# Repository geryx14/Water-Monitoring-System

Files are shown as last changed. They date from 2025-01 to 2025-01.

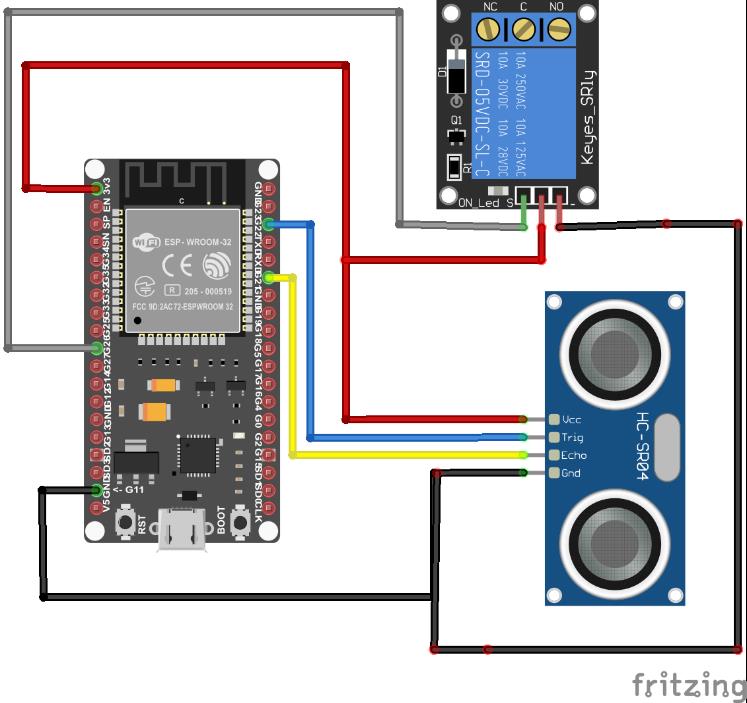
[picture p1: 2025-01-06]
Scematic Hardwere/Wiring ESP.jpg

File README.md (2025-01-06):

# IoT-Based Water Monitoring System

## Description
This project provides an affordable and efficient way to monitor water levels and quality using IoT technology. With real-time data transmission and cloud integration, it ensures better resource management.

## Key Features
- Real-time monitoring of water parameters
- Database integration for remote access
- Simple and scalable design
- to give saveral notifications alert to email and telegram

## Hardware Requirements
- ESP32 microcontroller
- Raspberry pi 4B
- ADS115 Analog Digital Converter
- Ultrasonic sensor (URM-09) : https://wiki.dfrobot.com/URM09_Ultrasonic_Sensor_(Gravity_Analog)_SKU_SEN0307
- Gravity: Analog Turbidity Sensor for Arduino LINK : https://www.dfrobot.com/product-1394.html?srsltid=AfmBOop4nN1BXaXB-rLAD9B4F6cB8y7F4hOIFvNodXXyrF563nFi_e-l
- Gravity: Analog pH Sensor / Meter Pro Kit for Arduino : https://www.dfrobot.com/product-1110.html
- DC PSU 5 Volt
- DC PSU 24 Volt
- Relay 5V DC
- Relay 3 fasa solidstate

## Required Libraries and Dependencies

To ensure the system works properly, install the following libraries and dependencies for ESP32, Raspberry Pi, and Node-RED.

### **ESP32 Libraries**
Ensure the following libraries are installed in the Arduino IDE or PlatformIO:

1. **WiFi Library**  
   - For ESP32 WiFi connectivity.  
   - Built-in with ESP32 core, or install via Board Manager.

2. **PubSubClient**  
   - For MQTT communication.  
   - Install via Arduino Library Manager:  
     ```
     Sketch > Include Library > Manage Libraries > Search for "PubSubClient"
     ```
3. **Ultrasonic sensor (URM-09)** 
   -For HC-SR04 ultrasonic sensor URM-09
   - Install via GitHub:  
     ```
       [[Ultrasonic](https://github.com/JRodrigoTech/Ultrasonic-HC-SR04](https://github.com/DFRobot/DFRobot_URM09))
     
     ```
### **Raspberry Pi Dependencies**
Install the following libraries or packages on your Raspberry Pi:

1. **I2C Communication**  
      first you must to active I2C Communication for raspberry pi
       1. "Sudo Raspi-config"
       2. Interface Options > I2C > Enable
     
4. **MQTT Library**
    Step two you must install MQTT library  
     sudo apt update
     sudo apt upgrade -y
     Sudo pip3 install paho-mqtt

3. **Sensor-Specific Libraries**  
   -For HC-SR04 ultrasonic sensor URM-09
   - Install via GitHub:  
     [[Ultrasonic](https://github.com/JRodrigoTech/Ultrasonic-HC-SR04](https://github.com/DFRobot/DFRobot_URM09))
   -for ADS115 Analog Digital Converter
    - Install via GitHub
      https://github.com/giobauermeister/ads1115-linux-rpi

### **Node-RED Dependencies**
Install the following custom nodes in Node-RED:

1. **Installation Steps:**  
    to use node-red with server for example install node-red in windows comment promt
    - npm install -g --unsafe-perm node-red

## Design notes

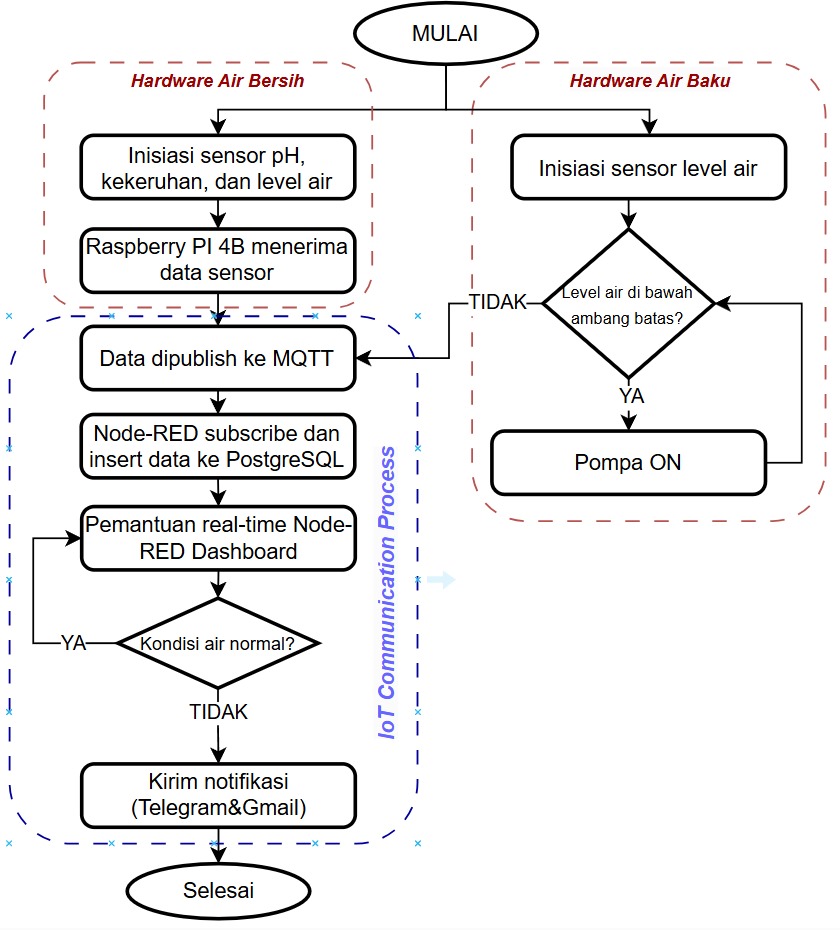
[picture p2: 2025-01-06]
Flow Chart.jpeg

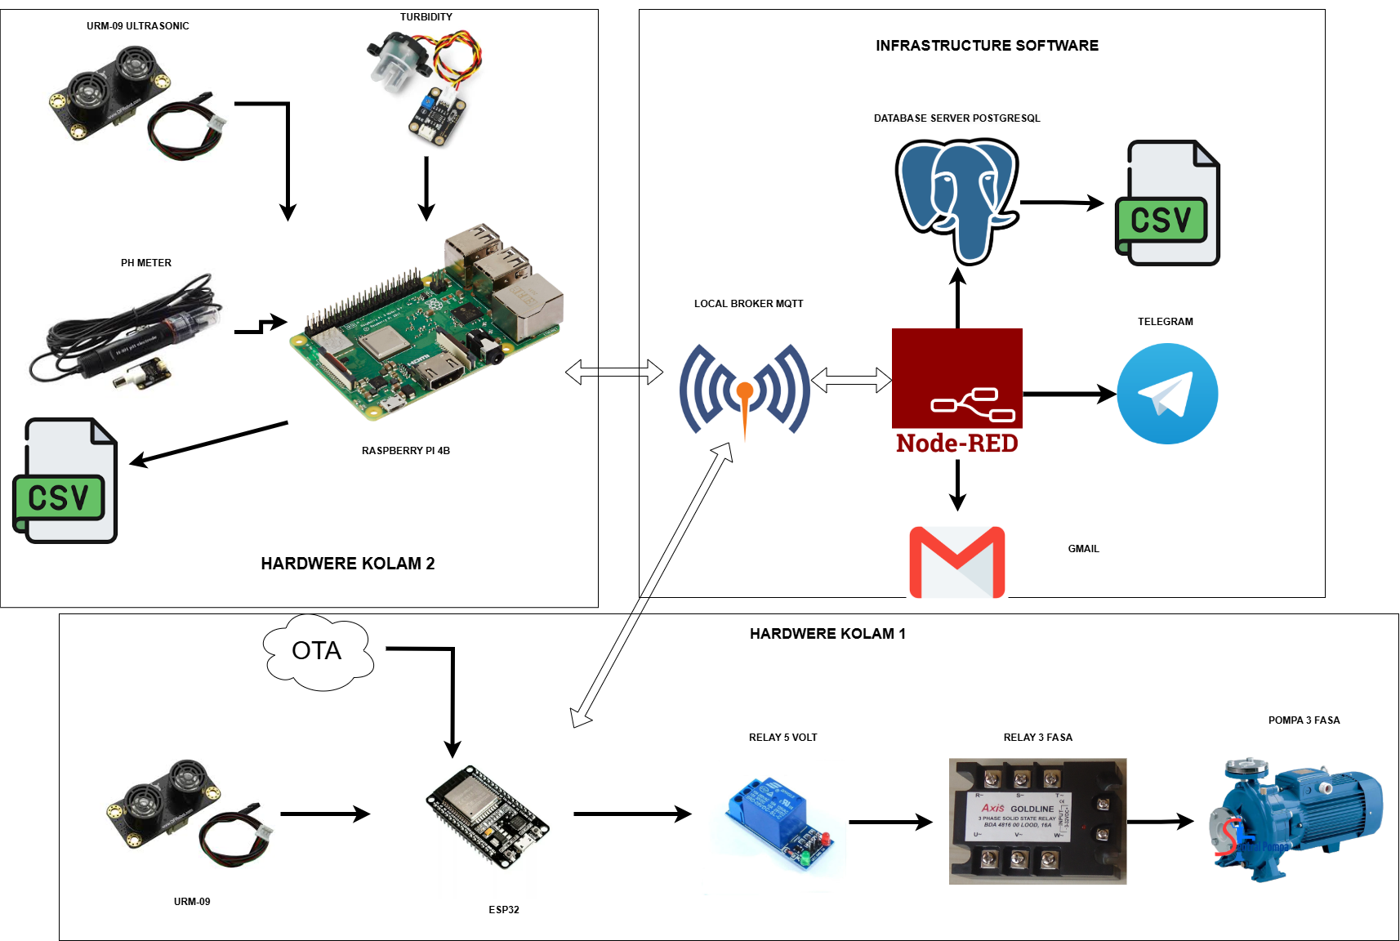
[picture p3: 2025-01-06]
Diagram Blok.png

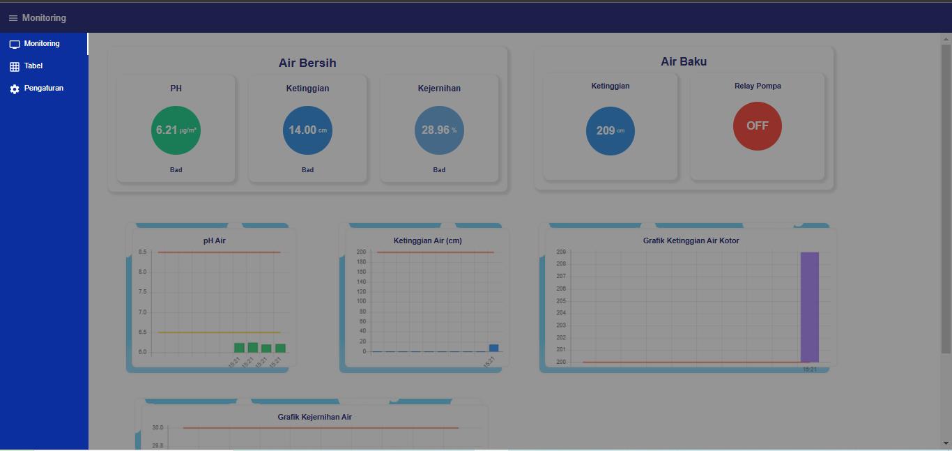
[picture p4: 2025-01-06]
Program Software/DASHBOARD.jpg

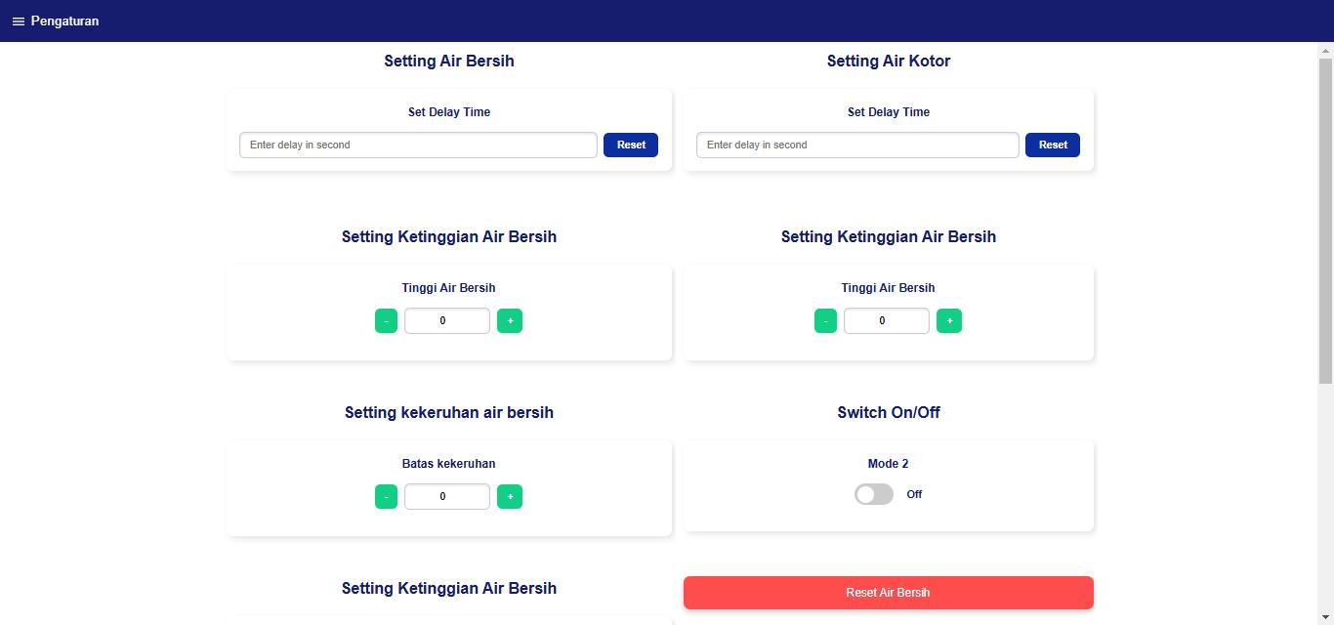
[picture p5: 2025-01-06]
Program Software/CONFIG.jpg

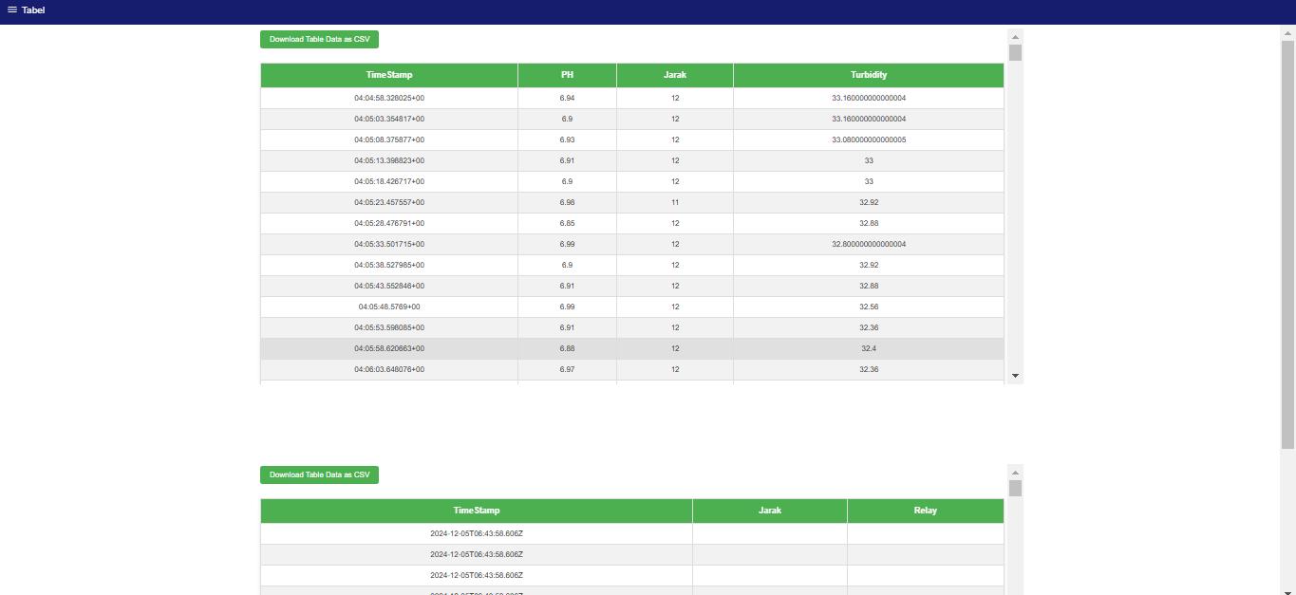
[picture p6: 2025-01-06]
Program Software/Database.jpg

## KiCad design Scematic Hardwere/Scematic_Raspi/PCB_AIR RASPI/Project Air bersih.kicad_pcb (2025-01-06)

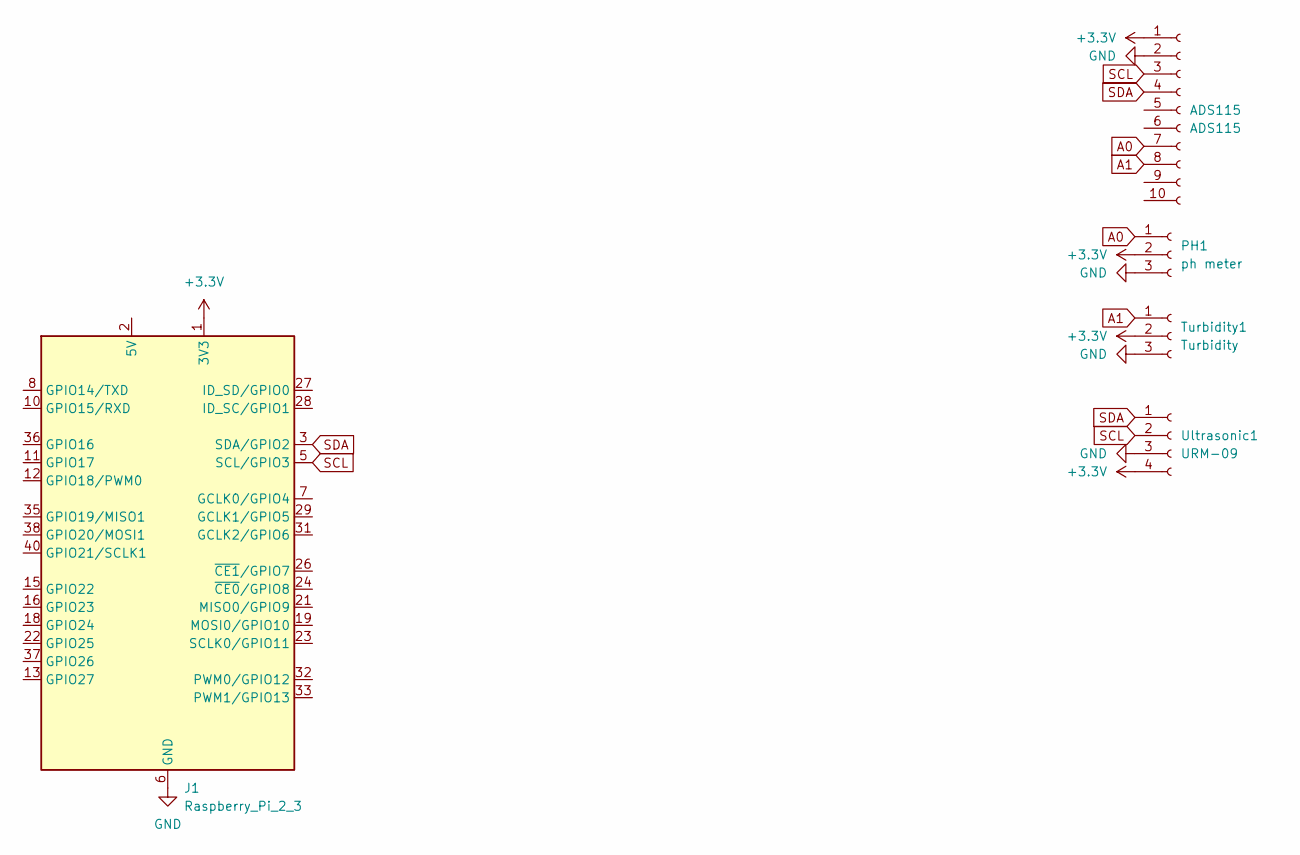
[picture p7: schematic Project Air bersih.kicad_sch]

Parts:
ADS115: ADS115; Hirose_DF13-10P-1.25DSA_1x10_P1.25mm_Vertical
J1: Raspberry_Pi_2_3; PinHeader_2x20_P2.54mm_Vertical
PH1: ph meter; JST_EH_B3B-EH-A_1x03_P2.50mm_Vertical
Turbidity1: Turbidity; JST_EH_B3B-EH-A_1x03_P2.50mm_Vertical
Ultrasonic1: URM-09; JST_EH_B4B-EH-A_1x04_P2.50mm_Vertical

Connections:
+3.3V: ADS115.1, J1.1 (3V3), J1.17 (3V3), PH1.2, Turbidity1.2, Ultrasonic1.4
A0: ADS115.7, PH1.1
A1: ADS115.8, Turbidity1.1
GND: ADS115.2, J1.6 (GND), J1.9 (GND), J1.14 (GND), J1.20 (GND), J1.25 (GND), J1.30 (GND), J1.34 (GND), J1.39 (GND), PH1.3, Turbidity1.3, Ultrasonic1.3
unnamed: J1.2 (5V), J1.4 (5V)
SCL: ADS115.3, J1.5 (SCL/GPIO3), Ultrasonic1.2
SDA: ADS115.4, J1.3 (SDA/GPIO2), Ultrasonic1.1

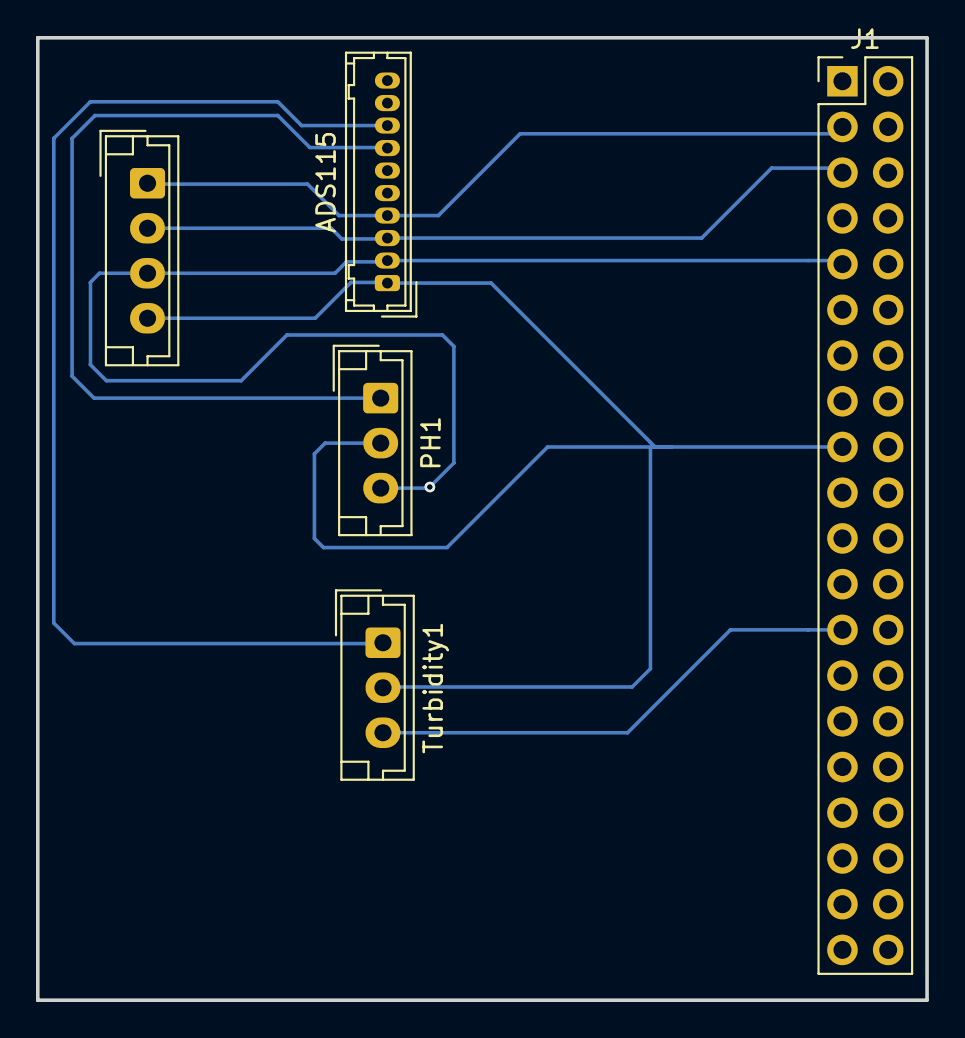
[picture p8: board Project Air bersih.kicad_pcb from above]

Board: 2 copper layers, 49.4 x 53.5 mm, 5 parts (0 on the bottom side), 7 nets.

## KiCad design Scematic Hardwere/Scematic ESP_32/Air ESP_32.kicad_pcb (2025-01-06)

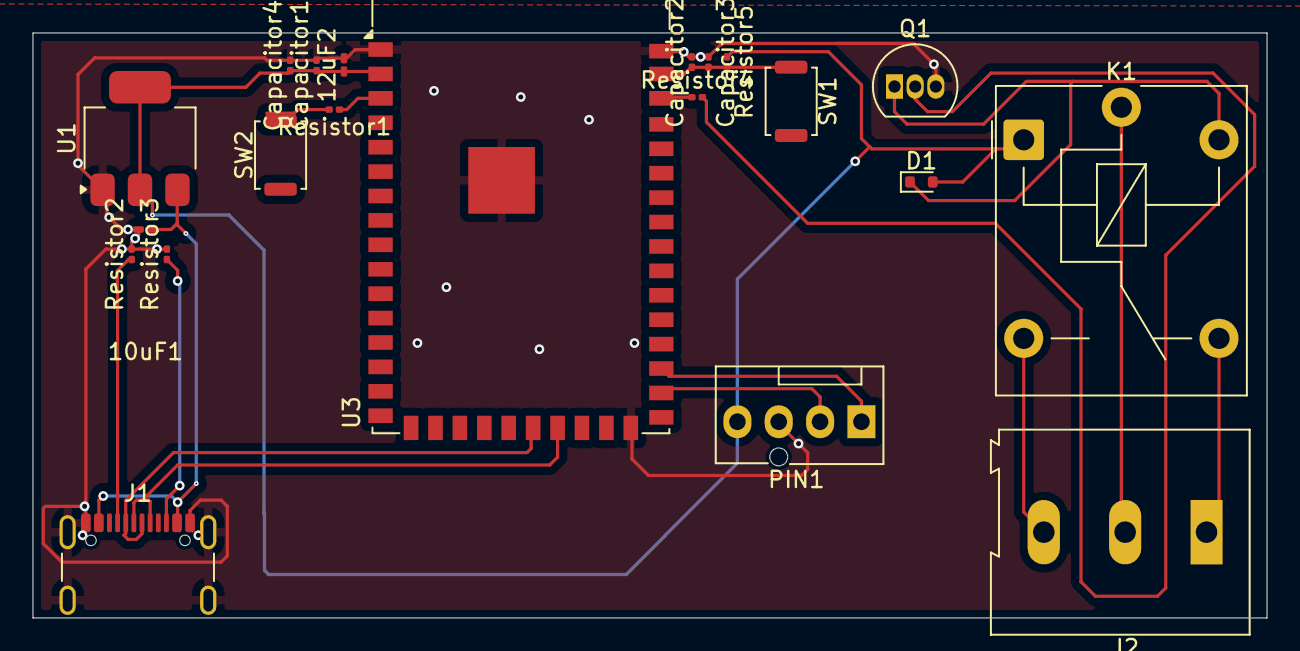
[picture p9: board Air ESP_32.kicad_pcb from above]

Board: 2 copper layers, 75.8 x 35.9 mm, 21 parts (0 on the bottom side), 18 nets.

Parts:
10uF1, 12uF2: c; C_0201_0603Metric_Pad0.64x0.40mm_HandSolder
Capacitor1: 10nf; C_0201_0603Metric
Capacitor2, Capacitor3: 1uF; C_0201_0603Metric
Capacitor4: 22uf; C_0201_0603Metric
D1: 1N4148WT; D_SOD-523
J1: USB_C_Receptacle_USB2.0_16P; USB_C_Receptacle_GCT_USB4105-xx-A_16P_TopMnt_Horizontal
J2: Screw_Terminal_01x03; TerminalBlock_Altech_AK300-3_P5.00mm
K1: FINDER-36.11; Relay_SPDT_Finder_36.11
PIN1: Ultrasonic URM-09; FanPinHeader_1x04_P2.54mm_Vertical
Q1: BC547; TO-92_Inline
Resistor1, Resistor4: 100R; R_0201_0603Metric
Resistor2, Resistor3, Resistor5: 10k; R_0201_0603Metric
SW1, SW2: SW_MEC_5G; SW_Push_SPST_NO_Alps_SKRK
U1: AMS1117; SOT-223-3_TabPin2
U3: ESP32-S2-WROVER

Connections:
+3.3V: 12uF2.1, Capacitor1.1, Capacitor4.1, D1.2 (A), K1.A1, PIN1.4, Resistor5.1, U1.2 (VO), U3.2 (3V3)
+5V: 10uF1.1, J1.A4 (VBUS), J1.A9 (VBUS), J1.B4 (VBUS), J1.B9 (VBUS), U1.3 (VI)
BOOT: Resistor1.1, U3.3 (IO00)
D+: J1.A6 (D+), J1.B6 (D+), U3.23 (USB_D+)
D-: J1.A7 (D-), J1.B7 (D-), U3.22 (USB_D-)
EN: Capacitor2.1, Capacitor3.2, Resistor5.2, SW1.1 (A), SW1.2 (A), U3.41 (EN)
GND: 10uF1.2, 12uF2.2, Capacitor1.2, Capacitor2.2, Capacitor3.1, Capacitor4.2, J1.A1 (GND), J1.A12 (GND), J1.B1 (GND), J1.B12 (GND), J1.S1 (SHIELD), PIN1.3, Q1.3 (E), Resistor2.2, Resistor3.2, U1.1 (ADJ), U3.1 (GND), U3.26 (GND), U3.42 (GND), U3.43 (GND)
unnamed: D1.1 (K), K1.A2, Q1.1 (C)
unnamed: J1.A5 (CC1), Resistor2.1
unnamed: J1.B5 (CC2), Resistor3.1
unnamed: J2.1, K1.12
unnamed: J2.2, K1.11
unnamed: J2.3, K1.14
unnamed: Q1.2 (B), Resistor4.2
unnamed: Resistor1.2, SW2.1 (A), SW2.2 (A)
R: Resistor4.1, U3.40 (IO46)
SCL: PIN1.2, U3.28 (IO34)
SDA: PIN1.1, U3.29 (IO35)

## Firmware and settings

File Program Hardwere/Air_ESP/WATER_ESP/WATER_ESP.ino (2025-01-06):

#include <WiFi.h>
#include <PubSubClient.h>
#include "DFRobot_URM09.h"


/* WiFi Configuration */
const char* ssid = "......";
const char* password = ".....;

/* MQTT Configuration */
const char* mqtt_server = ".....";
const int mqtt_port = 1883;
const char* mqtt_user = ".....";
const char* mqtt_password =  "......";

/* Ultrasonic Sensor */
DFRobot_URM09 URM09;

const int relayPin = 23; // GPIO untuk relay
unsigned long lastPublishTime = 0; // Waktu terakhir publish
unsigned long publishInterval = 1000;  // GPIO untuk relay
WiFiClient espClient;
PubSubClient client(espClient);

void connectToWiFi() {
  Serial.println("Connecting to WiFi...");
  WiFi.begin(ssid, password);

  // Tunggu sampai terhubung
  while (WiFi.status() != WL_CONNECTED) {
    delay(500);
    Serial.print(".");
  }
  Serial.println("\nWiFi connected.");
  Serial.print("IP Address: ");
  Serial.println(WiFi.localIP());
}

void connectToMQTT() {
  Serial.println("Connecting to MQTT...");
  client.setServer(mqtt_server, mqtt_port);
  while (!client.connected()) {
    if (client.connect("ESP32Client", mqtt_user, mqtt_password)) {
      Serial.println("MQTT connected");
      client.subscribe("inTopic");
      client.subscribe("airbaku/delay");
      client.subscribe("ultrasonic/reset"); 
    } else {
      Serial.print("Failed, rc=");
      Serial.println(client.state());
      delay(2000);
    }
  }
}
void callback(char* topic, byte* payload, unsigned int length) {
  payload[length] = '\0'; // Tambahkan null terminator
  String message = String((char*)payload);

  if (String(topic) == "airbaku/Relay") {
    if (message == "1") {
      digitalWrite(relayPin, HIGH); // Menyalakan relay
      Serial.println("Relay ON");
    } else if (message == "0") {
      digitalWrite(relayPin, LOW); // Mematikan relay
      Serial.println("Relay OFF");
    }
  } if (String(topic) == "airbaku/delay") {
    int newInterval = message.toInt();
    if (newInterval > 0) {
        publishInterval = newInterval * 1000; // Konversi detik ke milidetik
        Serial.print("Interval publish diubah ke: ");
        Serial.print(publishInterval / 1000); // Cetak dalam satuan detik
        Serial.println(" detik");
    } else {
        Serial.println("Invalid interval received.");
    }
}
    else if (String(topic) == "airbaku/reset") { 
    if (message == "1") { 
      Serial.println("Reset command received. Restarting device...");
      delay(1000); 
      ESP.restart();
    }
  }
}

void setup() {
  Serial.begin(115200);
  pinMode(relayPin, OUTPUT);
  digitalWrite(relayPin, LOW);

  connectToWiFi();

  // Inisialisasi sensor setelah Wi-Fi
  Serial.println("Initializing ultrasonic sensor...");
  while (!URM09.begin()) {
    Serial.println("I2C device not detected. Retrying...");
    delay(1000);
  }
  URM09.setModeRange(MEASURE_MODE_AUTOMATIC, MEASURE_RANG_500);
  Serial.println("Ultrasonic sensor initialized.");

  // Hubungkan ke MQTT
  client.setCallback(callback);
  connectToMQTT();
}

void loop() {
  if (!client.connected()) {
    connectToMQTT();
  }
  client.loop();

  unsigned long currentMillis = millis();
  if (currentMillis - lastPublishTime >= publishInterval) {
    lastPublishTime = currentMillis;

    float distance = URM09.getDistance();
    if (distance <= 0 || distance > 500) {
      Serial.println("Invalid distance data!");
      return;
    }
    bool relayStatus = digitalRead(relayPin);
    char payload[100];
    snprintf(payload, sizeof(payload), "{\"distance\": %.2f, \"relay_status\": %s}", distance, relayStatus ? "false" : "true");

    client.publish("ultrasonic/data", payload);
    Serial.printf("Published: %s\n", payload);
  }
}

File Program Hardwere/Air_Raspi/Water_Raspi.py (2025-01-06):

import time
import json
import threading
import busio
import board
import paho.mqtt.client as mqtt
from adafruit_ads1x15.analog_in import AnalogIn
from adafruit_ads1x15.ads1015 import ADS1015
import sys
from queue import Queue
sys.path.append("/home/raspi/Projek air/python/raspberrypi")  
from DFRobot_URM09 import DFRobot_URM09_IIC

# Konstanta kalibrasi 
tegangan_ph7 = 1.5  
tegangan_ph4 = 2.03  
slope = (7.0 - 4.0) / (tegangan_ph7 - tegangan_ph4)
intercept = 7 - (slope * tegangan_ph7)  
running = threading.Event()
running.set()
data_queue = Queue()

# Konfigurasi MQTT
mqtt_broker = "........"  # Alamat broker MQTT
mqtt_topic = "........."        # Topik untuk data sensor
mqtt_delay_topic = "monitoringenergy/delay"  # Topik untuk delay pengiriman data
mqtt_username = "......"     # Username untuk autentikasi
mqtt_password = "........"  # Password untuk autentikasi
client = mqtt.Client()

# Variabel untuk mengatur delay pengiriman data
delay_time = 2  # Default delay 2 detik

# Fungsi untuk menangani koneksi ke broker MQTT
def on_connect(client, userdata, flags, rc):
    if rc == 0:
        print("Terhubung ke broker MQTT!")
        # Setelah terhubung, subscribe ke topik untuk delay
        client.subscribe(mqtt_delay_topic)
    else:
        print("Gagal terhubung ke broker MQTT, kode:", rc)

# Fungsi untuk menangani pesan yang diterima dari topik
def on_message(client, userdata, msg):
    global delay_time
    try:
        # Mengambil pesan yang diterima dan mengonversinya menjadi float
        message = float(msg.payload.decode())
        print(f"Menerima pesan baru untuk delay: {message} detik")
        # Update delay_time berdasarkan pesan yang diterima
        delay_time = message
    except ValueError:
        print(f"Pesan tidak valid diterima pada {msg.topic}: {msg.payload}")

# Fungsi untuk menghubungkan ke broker MQTT
def connect_mqtt():
    try:
        # Set username dan password untuk autentikasi
        client.username_pw_set(mqtt_username, mqtt_password)
        
        # Terhubung ke broker MQTT
        client.connect(mqtt_broker)
        client.on_connect = on_connect
        client.on_message = on_message
        client.loop_start()  # Memulai loop MQTT untuk menangani pengiriman dan penerimaan pesan
    except Exception as e:
        print(f"Gagal terhubung ke broker MQTT: {e}")

# Inisialisasi I2C dan sensor
i2c = busio.I2C(board.SCL, board.SDA)
ads = ADS1015(i2c)
chan_ph = AnalogIn(ads, 0)  # Sensor pH pada channel 0
turbidity_channel = AnalogIn(ads, 1)  # Sensor turbidity pada channel 1
urm09 = DFRobot_URM09_IIC(0x01, 0x11)

# Fungsi untuk mengonversi tegangan menjadi nilai pH
def konversi_tegangan_ke_ph(tegangan):
    return round(slope * tegangan + intercept, 2)

def baca_sensor_ads():
    while running.is_set():
        try:
            # Baca sensor pH dengan interval 2 detik
            tegangan_ph = chan_ph.voltage
            nilai_ph = konversi_tegangan_ke_ph(tegangan_ph)
            data_queue.put({"pH": nilai_ph})
            time.sleep(2)  # Interval pembacaan untuk pH

            # Baca sensor turbidity dengan interval 3 detik
            voltage_turbidity = turbidity_channel.voltage
            turbidity_value = (voltage_turbidity / 5.0) * 100
            data_queue.put({"turbidity": turbidity_value})
            time.sleep(3)  # Interval pembacaan untuk turbidity
        except Exception as e:
            print(f"Kesalahan membaca sensor ADS: {e}")

def baca_ultrasonik():
    while running.is_set():
        try:
            urm09.set_mode_range(urm09._MEASURE_MODE_AUTOMATIC, urm09._MEASURE_RANG_500)
            jarak = urm09.get_distance()
            if jarak is not None:
                data_queue.put({"jarak": jarak})
                time.sleep(2)  # Simulasi pembacaan setiap 2 detik
            else:
                print("Gagal membaca jarak, data None.")
        except Exception as e:
            print(f"Kesalahan membaca sensor ultrasonik: {e}")

# Fungsi untuk mengirim data ke broker MQTT
def kirim_data_mqtt(data):
    try:
        client.publish(mqtt_topic, json.dumps(data))
        print(f"Data dikirim ke MQTT: {json.dumps(data)}", end="\r")
    except Exception as e:
        print(f"Gagal mengirim data ke MQTT: {e}")

# Fungsi utama untuk menjalankan simulasi
def main():
    # Koneksi ke broker MQTT
    connect_mqtt()

    # Jalankan pembacaan sensor dalam thread terpisah
    threading.Thread(target=baca_sensor_ads).start()
    threading.Thread(target=baca_ultrasonik).start()
    
    # Loop utama untuk mengambil dan menampilkan data
    while running.is_set():
        try:
            # Membuat dictionary kosong untuk menyimpan data sensor yang lengkap
            data = {"pH": None, "jarak": None, "turbidity": None}
            
            # Mengisi data dari queue hingga semua sensor memiliki nilai
            while None in data.values():
                if not data_queue.empty():
                    # Update data dari queue jika ada yang baru
                    data.update(data_queue.get())
                    
                print(f"Data sensor: {json.dumps(data)}", end='\r')
                    
            # Flush output buffer untuk memastikan output langsung tampil
            sys.stdout.flush()
            
            # Kirim data ke broker MQTT
            kirim_data_mqtt(data)
            
            time.sleep(delay_time)  # Delay sesuai dengan nilai yang diterima dari MQTT
        except Exception as e:
            print(f"Kesalahan saat menjalankan PROGRAN: {e}")

if _name_ == "_main_":
    try:
        main()  # Memulai simulasi pembacaan sensor
    except KeyboardInterrupt:
        print("Menutup ")
        running.clear()
        client.loop_stop()  # Menghentikan loop MQTT
        time.sleep(3)  # Waktu untuk menghentikan semua thread
        print(" dihentikan.")
